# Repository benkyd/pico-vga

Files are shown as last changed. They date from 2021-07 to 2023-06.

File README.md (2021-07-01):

# Pico-VGA: A micro controller video card

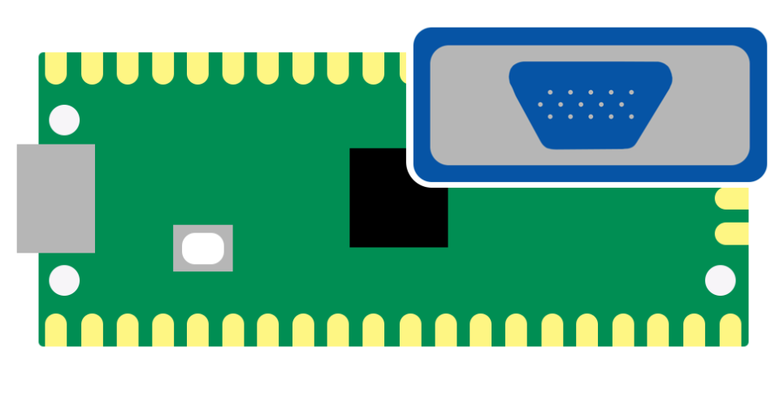
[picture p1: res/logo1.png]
PicoVGA


A VGA Driver made from a Raspberry Pi Pico with the eventual goal of being an acting video card.

I also plan to experiment with 3D rendering on it.

## PCB
Kicad and fabrication files can be found in `kicad/`

## Contributors
- [Alexandre Rouma](https://github.com/AlexandreRouma) (Logo Design)
- [Joshua Webster](https://github.com/w3bb0) (PCB Design)

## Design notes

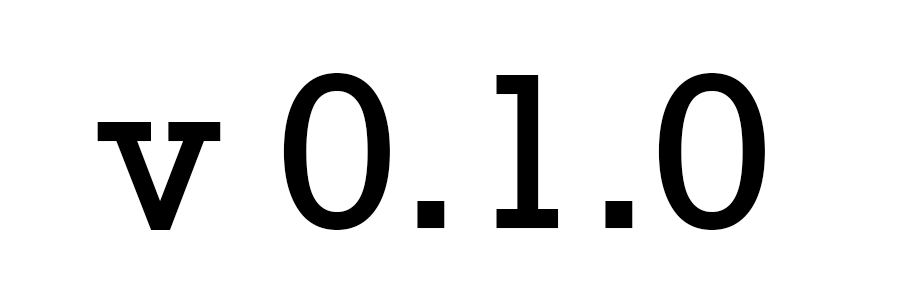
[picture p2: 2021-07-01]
designs/Product Version.png

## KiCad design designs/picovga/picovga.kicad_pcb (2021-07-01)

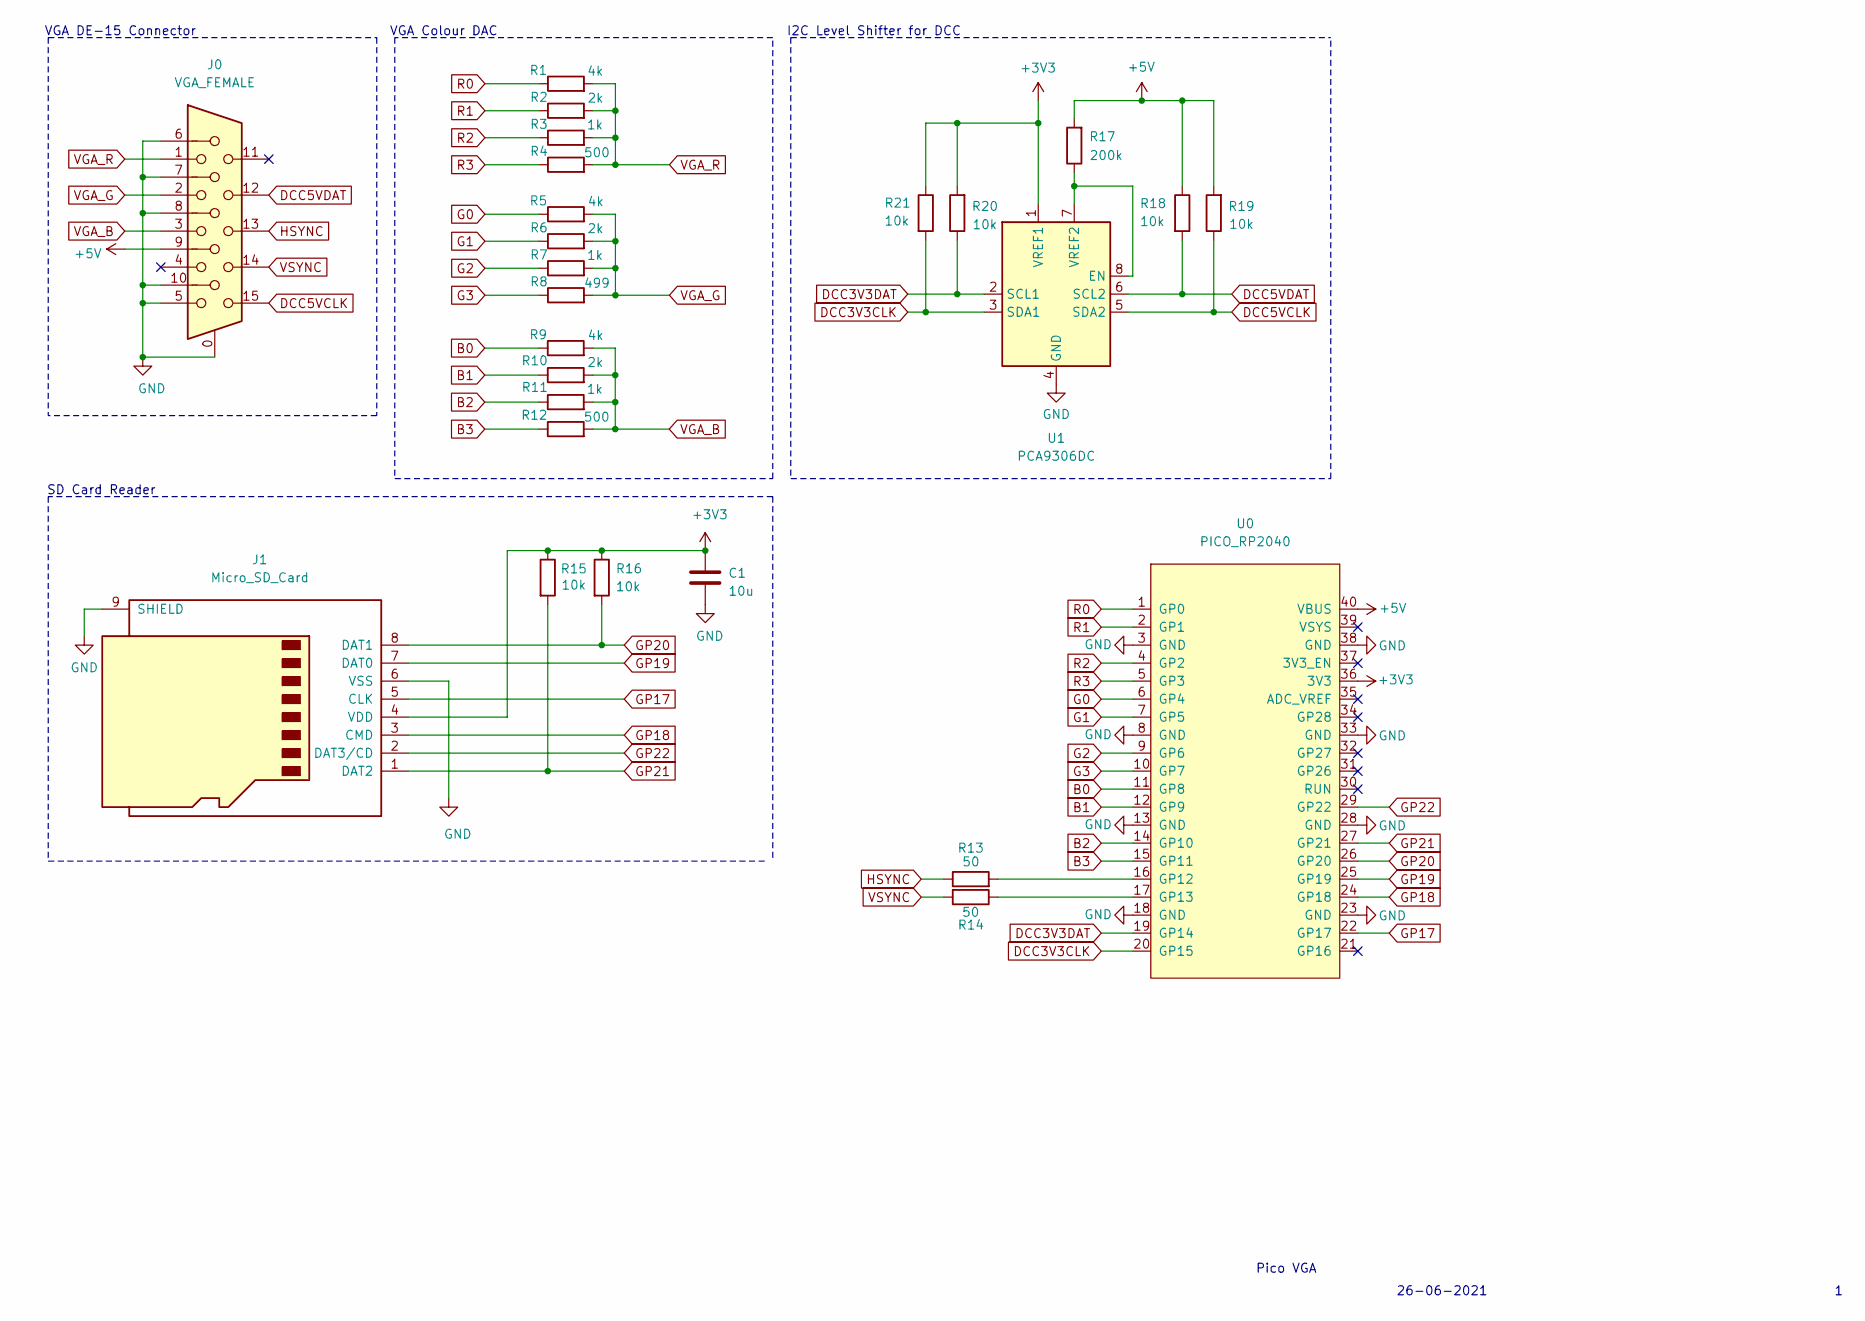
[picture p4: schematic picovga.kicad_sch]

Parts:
C1: 10u; C_0805_2012Metric_Pad1.18x1.45mm_HandSolder
J0: VGA_FEMALE; XM4L1542132
J1: Micro_SD_Card; microSD_HC_Hirose_DM3AT-SF-PEJM5
R1, R5, R9: 4k; R_0805_2012Metric_Pad1.20x1.40mm_HandSolder
R2, R6, R10: 2k; R_0805_2012Metric_Pad1.20x1.40mm_HandSolder
R3, R7, R11: 1k; R_0805_2012Metric_Pad1.20x1.40mm_HandSolder
R4, R12: 500; R_0805_2012Metric_Pad1.20x1.40mm_HandSolder
R8: 499; R_0805_2012Metric_Pad1.20x1.40mm_HandSolder
R13, R14: 50; R_0805_2012Metric_Pad1.20x1.40mm_HandSolder
R15, R16, R18, R19, R20, R21: 10k; R_0805_2012Metric_Pad1.20x1.40mm_HandSolder
R17: 200k; R_0805_2012Metric_Pad1.20x1.40mm_HandSolder
U0: PICO_RP2040; raspberrypi-pico-module
U1: PCA9306DC; VSSOP-8_2.3x2mm_P0.5mm

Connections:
+3V3: C1.1, J1.4 (VDD), R15.1, R16.1, R20.2, R21.1, U0.36 (3V3), U1.1 (VREF1)
+5V: J0.9, R17.2, R18.1, R19.2, U0.40 (VBUS)
B0: R9.1, U0.11 (GP8)
B1: R10.1, U0.12 (GP9)
B2: R11.1, U0.14 (GP10)
B3: R12.1, U0.15 (GP11)
DCC3V3CLK: R21.2, U0.20 (GP15), U1.3 (SDA1)
DCC3V3DAT: R20.1, U0.19 (GP14), U1.2 (SCL1)
DCC5VCLK: J0.15, R19.1, U1.5 (SDA2)
DCC5VDAT: J0.12, R18.2, U1.6 (SCL2)
G0: R5.1, U0.6 (GP4)
G1: R6.1, U0.7 (GP5)
G2: R7.1, U0.9 (GP6)
G3: R8.1, U0.10 (GP7)
GND: C1.2, J0.0, J0.5, J0.6, J0.7, J0.8, J0.10, J1.6 (VSS), J1.9 (SHIELD), U0.3 (GND), U0.8 (GND), U0.13 (GND), U0.18 (GND), U0.23 (GND), U0.28 (GND), U0.33 (GND), U0.38 (GND), U1.4 (GND)
GP17: J1.5 (CLK), U0.22 (GP17)
GP18: J1.3 (CMD), U0.24 (GP18)
GP19: J1.7 (DAT0), U0.25 (GP19)
GP20: J1.8 (DAT1), R16.2, U0.26 (GP20)
GP21: J1.1 (DAT2), R15.2, U0.27 (GP21)
GP22: J1.2 (DAT3/CD), U0.29 (GP22)
HSYNC: J0.13, R13.1
unnamed: R13.2, U0.16 (GP12)
unnamed: R14.1, U0.17 (GP13)
unnamed: R17.1, U1.7 (VREF2), U1.8 (EN)
R0: R1.1, U0.1 (GP0)
R1: R2.1, U0.2 (GP1)
R2: R3.1, U0.4 (GP2)
R3: R4.1, U0.5 (GP3)
VGA_B: J0.3, R9.2, R10.2, R11.2, R12.2
VGA_G: J0.2, R5.2, R6.2, R7.2, R8.2
VGA_R: J0.1, R1.2, R2.2, R3.2, R4.2
VSYNC: J0.14, R14.2
no_connect_34: J0.11
no_connect_35: J0.4
no_connect_36: U0.21 (GP16)
no_connect_37: U0.30 (RUN)
no_connect_38: U0.31 (GP26)
no_connect_39: U0.32 (GP27)
no_connect_40: U0.34 (GP28)
no_connect_41: U0.35 (ADC_VREF)
no_connect_42: U0.37 (3V3_EN)
no_connect_43: U0.39 (VSYS)

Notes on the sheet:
SD Card Reader
VGA DE-15 Connector
VGA Colour DAC
I2C Level Shifter for DCC
Pico VGA
26-06-2021

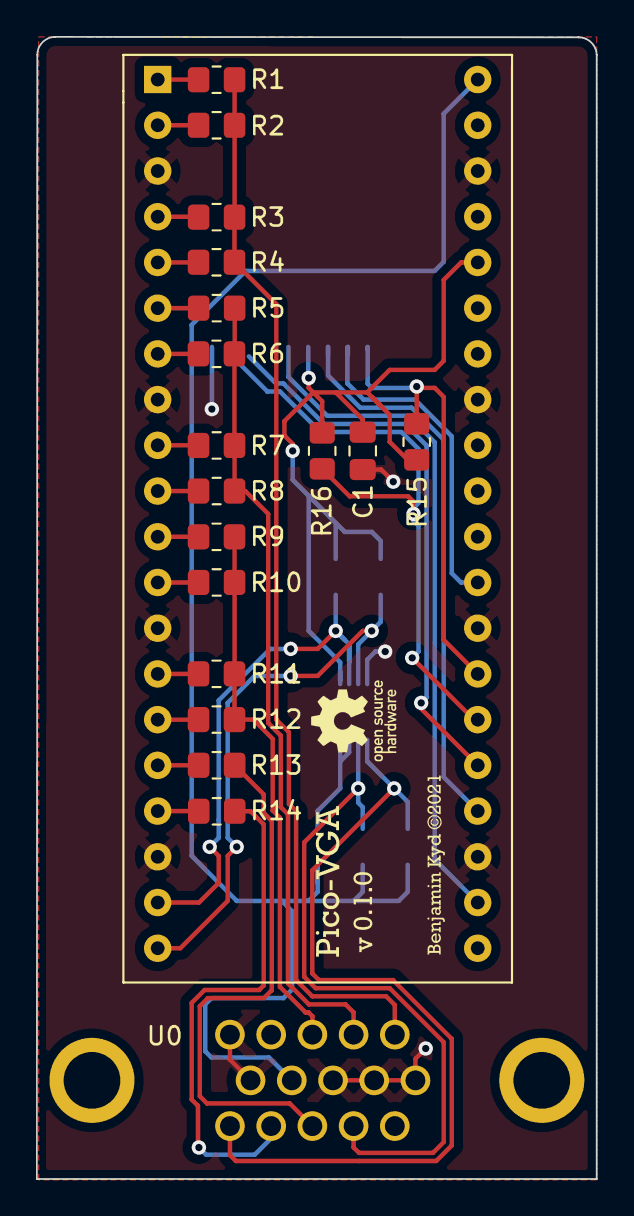
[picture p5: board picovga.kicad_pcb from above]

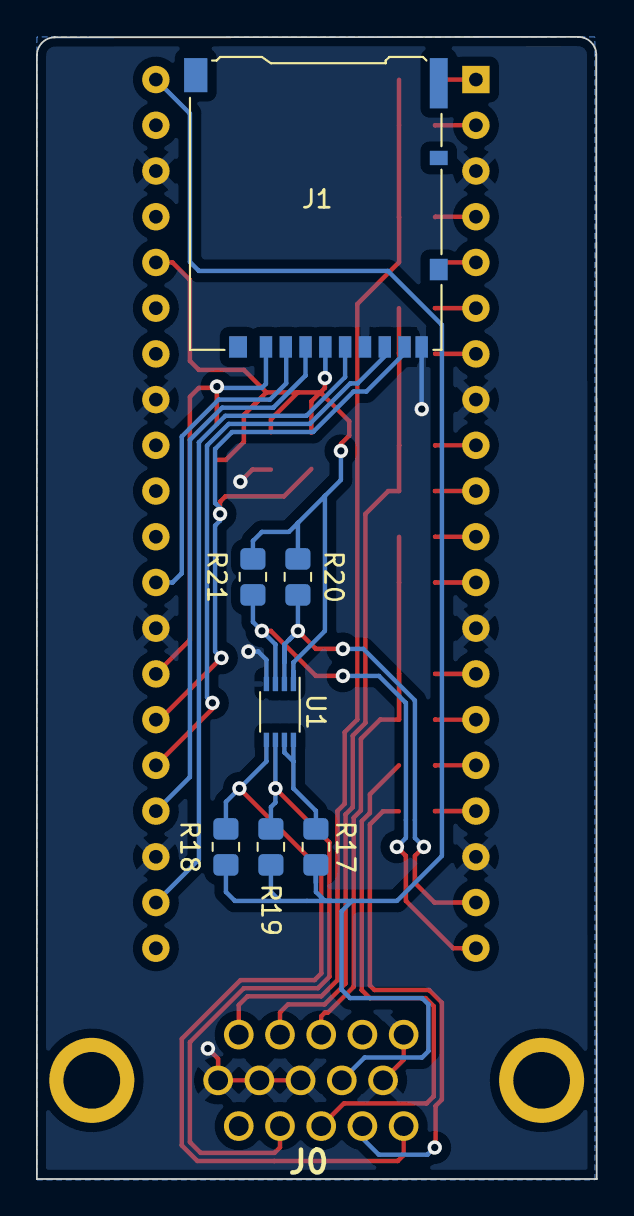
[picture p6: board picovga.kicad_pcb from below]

Board: 2 copper layers, 31.1 x 63.5 mm, 29 parts (8 on the bottom side), 33 nets.

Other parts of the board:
G: LOGO; name-logo
G#2: LOGO; product-version
G#3: LOGO; product-logo

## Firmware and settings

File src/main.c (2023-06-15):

// Copyright Benjamin Kyd 2021 All Rights Reserved

// PIN LAYOUT
// PIN 0-3 RED DAC
// PIN 4-7 GREEN DAC
// PIN 8-11 BLUE DAC
// PIN 12 HSYNC
// PIN 13 VSYNC

#include <stdio.h>
#include "pico/stdlib.h"
#include "hardware/clocks.h"
#include "hardware/pio.h"
#include "hardware/dma.h"
#include "hardware/irq.h"

#include "vga.pio.h"

typedef struct video_timing {
    uint32_t clock_freq;

    uint16_t h_active;
    uint16_t v_active;

    uint16_t h_front_porch;
    uint16_t h_pulse;
    uint16_t h_total;
    uint8_t h_sync_polarity;

    uint16_t v_front_porch;
    uint16_t v_pulse;
    uint16_t v_total;
    uint8_t v_sync_polarity;

    uint8_t enable_clock;
    uint8_t clock_polarity;

    uint8_t enable_den;
} video_timing_t;

const video_timing_t vga_timing_800x600_60 =
{
    .clock_freq = 38400000,

    .h_active = 800,
    .v_active = 600,

    .h_front_porch = 4 * 8,
    .h_pulse = 10 * 8,
    .h_total = 128 * 8,
    .h_sync_polarity = 0,

    .v_front_porch = 1,
    .v_pulse = 3,
    .v_total = 625,
    .v_sync_polarity = 0,

    .enable_clock = 0,
    .clock_polarity = 0,

    .enable_den = 0
};

static inline void vga_program_init(PIO pio, uint sm, uint offset, uint pin) {

    pio_gpio_init(pio, pin);
    pio_gpio_init(pio, pin+1);
    pio_sm_set_consecutive_pindirs(pio, sm, pin, 2, true);

    pio_sm_config c = vga_program_get_default_config(offset);

    sm_config_set_out_pins(&c, pin, 2);

    sm_config_set_fifo_join(&c, PIO_FIFO_JOIN_TX);
    sm_config_set_out_shift(&c, false, true, 2);

    pio_sm_init(pio, sm, offset, &c);
    pio_sm_set_enabled(pio, sm, true);
}

int main() {
    PIO pio = pio0;
    uint offset = pio_add_program(pio, &vga_program);
    uint sm = pio_claim_unused_sm(pio, true);

    vga_program_init(pio, sm, offset, 12);

    while (true) {
        pio_sm_put_blocking(pio, sm, 0b01);
        sleep_ms(20);
        pio_sm_put_blocking(pio, sm, 0b10);
        sleep_ms(20);
    }
}

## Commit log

2021-06-28 add KiCAD PCB Files and more pio code
    [picovga-B_Cu.gbr, picovga-B_Mask.gbr, picovga-B_Paste.gbr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]
2021-07-01 board off for fabrication
    [picovga-B_Cu.gbr, picovga-B_Mask.gbr, picovga-B_Paste.gbr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]
2021-07-01 fixed the error
    [picovga.kicad_sch]
2023-06-09 Seeing if i can get this to work
    [picovga-B_Cu.gbr, picovga-B_Mask.gbr, picovga-B_Paste.gbr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]
